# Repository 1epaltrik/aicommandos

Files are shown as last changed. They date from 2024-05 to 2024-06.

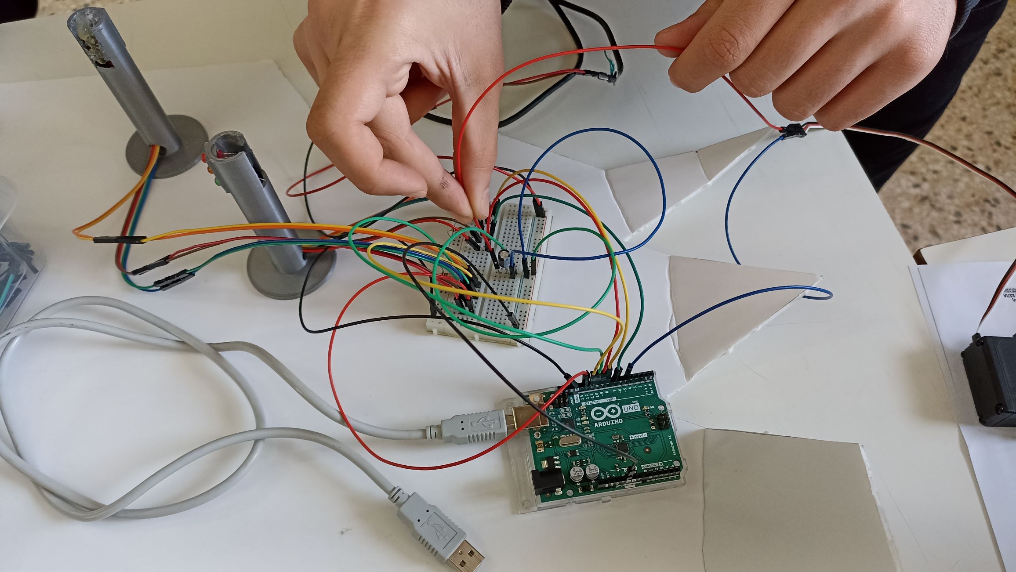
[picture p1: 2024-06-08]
photos/AICommandos13.jpg

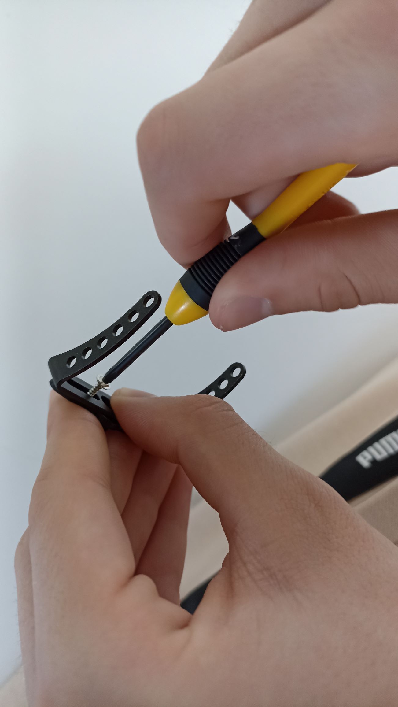
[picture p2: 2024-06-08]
photos/AICommandos12.jpg

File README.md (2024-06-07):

<h1>Ρύθμιση σηματοδοτών κυκλοφορίας
με Τεχνητή Νοημοσύνη</h1>
Είμαστε η ομάδα AI Commandos από το 1ο ΕΠΑΛ Τρικάλων και υλοποιήσαμε το έργο "Ρύθμιση σηματοδοτών κυκλοφορίας με τεχνητή νοημοσύνη".
<h2>Έρευνα</h2>
<h3>Μελέτη υπάρχουσας κατάστασης</h3>
Ένα τεράστιο πρόβλημα των σύγχρονων πόλεων είναι το πρόβλημα της κυκλοφοριακής συμφόρησης, που αφορά όχι μόνο τις μεγάλες μητροπόλεις, αλλά πλέον εμφανίζεται έντονα και στις μικρότερες πόλεις, όπως είναι τα Τρίκαλα.</p>
<p>Ενδεικτικά δείτε το δημοσίευμα: https://trikalain.gr/polys-kosmos-sta-trikala-gia-tis-giortes-tou-pascha-kykloforiako-komfouzio-stous-dromou-tis-polis/</p>
<p>Κυκλοφοριακή συμφόρηση (κοινώς μποτιλιάρισμα) ονομάζεται η κατάσταση στα οδικά δίκτυα που χαρακτηρίζεται από ουρές οχημάτων και χαμηλότερες ταχύτητες μέχρι και ακινησία. Η κυκλοφοριακή συμφόρηση στα αστικά οδικά δίκτυα έχει αυξηθεί σημαντικά από τη δεκαετία του 1950. (Ορισμός από τη Wikipedia).
Οι αρνητικές συνέπειες είναι πολλές: χαμένος χρόνος για οδηγούς και επιβάτες, αυξημένες εκπομπές ρύπων, μεγαλύτερη κατανάλωση καυσίμων, σπατάλη ενέργειας, δημιουργία εκνευρισμού και άγχους, υποβάθμιση της ποιότητας ζωής κλπ.</p>
<h3>Σαφής ορισμός προβλήματος</h3>
<p>Η κυκλοφοριακή συμφόρηση σε μια πόλη μπορεί να προκαλείται από πολλές αιτίες, μία από τις οποίες είναι οι αστικές διασταυρώσεις δύο δρόμων με φανάρια, όπου ο ένας δρόμος έχει μεγαλύτερη κίνηση από τον άλλον.
Σε αυτή την περίπτωση παρατηρείται το φαινόμενο να δημιουργούνται μεγάλες ουρές στο δρόμο με τη μεγαλύτερη κίνηση, ενώ στο δρόμο μικρότερης κίνησης δημιουργούνται μικρές ή και καθόλου ουρές, καθώς ο χρονισμός των φαναριών είναι σταθερός και δεν λαμβάνει υπόψη την τρέχουσα κίνηση σε κάθε δρόμο.</p>
<p>Το φαινόμενο αυτό είναι περισσότερο συνηθισμένο στις μικρές πόλεις, όπως είναι τα Τρίκαλα.</p>

<h2>Σχεδιασμός</h2>
<h3>Σαφής ορισμός προτεινόμενης λύσης</h3>
<p>Η λύση που προτείνουμε είναι να δίνεται προτεραιότητα στο δρόμο που παρατηρείται μεγαλύτερη κίνηση, με κατάλληλη ρύθμιση των φαναριών έτσι ώστε το πράσινο να διαρκεί περισσότερο στο δρόμο μεγαλύτερης κίνησης, για να εκτονώνεται η κυκλοφορία.</p>
<p>Για την αναγνώριση του δρόμου μεγαλύτερης κίνησης δημιουργήσαμε ένα σύστημα με κάμερα και λογισμικό αναγνώρισης οχημάτων, μέσω τεχνικών επεξεργασίας εικόνας και βίντεο και με χρήση τεχνητής νοημοσύνης.</p>
<p>Το σύστημα ελέγχει τον αριθμό των αυτοκινήτων που προστίθενται στην ουρά ενός δρόμου και περιμένουν στο κόκκινο φανάρι. Όταν η ουρά αρχίζει να μεγαλώνει πάνω από ένα όριο, γίνεται ανάλογη ρύθμιση των φωτεινών σηματοδοτών ώστε να αποτραπεί η συμφόρηση.
Πιο συγκεκριμένα αυξάνεται η διάρκεια του πράσινου στο δρόμο με τη μεγαλύτερη ουρά, ενώ μειώνεται στον άλλο δρόμο.</p>
<p>Η κάμερα είναι στερεωμένη πάνω σε βάση και περιστρέφεται με τη βοήθεια ενός κινητήρα, έτσι ώστε να ελέγχει και τους δύο δρόμους της διασταύρωσης. Η κάμερα κοιτάζει πάντα στο δρόμο που έχει κόκκινο για να ελέγχει την ουρά που σχηματίζεται.</p>
<p>Με αυτό τον τρόπο η ρύθμιση των φαναριών επαναλαμβάνεται και προσαρμόζεται δυναμικά ανάλογα με την κίνηση που εμφανίζεται σε κάθε δρόμο της διασταύρωσης.</p>
<h3>Πρωτοτυπία λύσης</h3>
<p>Η χρήση της Τεχνητής Νοημοσύνης είναι προφανώς απαραίτητη σε ένα σύστημα ολοκληρωμένης διαχείρισης του κυκλοφοριακού προβλήματος, όπως φαίνεται και σε διάφορα δημοσιεύματα, για παράδειγμα δείτε: https://www.motori.gr/sto-kokkino-to-kykloforiako-tis-athinas-ta-fanaria-apoktoun-techniti-noimosyni/</p>
<p>Ωστόσο για τη λύση που προτείνουμε δεν βρήκαμε καμία συγκεκριμένη αναφορά, οπότε θεωρούμε ότι είναι πρωτότυπη.</p>
<h3>Κόστος</h3>
<p>Το συνολικό κόστος για το σύστημα ανέρχεται στα 160 ευρώ περίπου.</p>
<h3>Λίστα υλικών και εργαλείων</h3>
<table border=1 cellspacing=0>
<tr><th>Υλικό</th>
<th>Τιμή</th></tr>
<tr><td>Τροφοδοτικό 12V 3A</td>
<td>7.20</td></tr>
<tr><td>Jumper Wires</td>
<td>4.40</td></tr>
<tr><td>Πλακέτα Δοκιμών</td>
<td>3.20</td></tr>
<tr><td>Arduino UNO R4 WiFi</td>
<td>32.80</td></tr>
<tr><td>Servo Standard 7.5kg.cm Metal Gears</td>
<td>16.90</td></tr>
<tr><td>Gravity HUSKYLENS AI Machine Vision Sensor</td>
<td>69.90</td></tr>
<tr><td>Νήμα 3D εκτύπωσης</td>
<td>25.00</td></tr>
</table>

<h3>Σχέδια</h3>
<p>Όλα τα σχέδια του κυκλώματος και των αντικειμένων 3D που εκτυπώσαμε για τη μακέτα είναι αναρτημένα στο <a href="https://github.com/1epaltrik/aicommandos/tree/956ff1dd9cedd848da6d70585bad451899f95dd7/hardware-design"> github</a>.</p>
<h3>Βασικός αλγόριθμος</h3>
<ol>
<li>Αρχικά ορίζουμε αρχικές τιμές για τη διάρκεια των κόκκινων φαναριών, πχ και τα δύο κόκκινα φανάρια να διαρκούν 6 sec.</li>
<li>Αρχίζει η λειτουργία των φαναριών: ανάβει κόκκινο στο δρόμο 1.</li>
<li>Αμέσως η κάμερα περιστρέφεται προς το δρόμο 1 και μετρά τα αυτοκίνητα που περιμένουν στην ουρά.</li>
<li>Αν η ουρά ξεπεράσει έναν αριθμό αυτοκινήτων (πχ 2 στο παράδειγμα επίδειξης), τότε μηδενίζεται ο υπολειπόμενος χρόνος του κόκκινου στο δρόμο 1 και αλλάζουν οι χρονισμοί των φαναριών: στο δρόμο 1 (που παρατηρήθηκε η ουρά) το πράσινο θα διαρκεί περισσότερο, πχ 25 sec, ενώ στον άλλο δρόμο 5 sec.</li>
<li>Συνεχίζεται η ακολουθία των φαναριών: ανάβει κόκκινο στο δρόμο 2.</li>
<li>Η κάμερα περιστρέφεται προς το δρόμο 2 και μετρά τα αυτοκίνητα που περιμένουν στην ουρά.</li>
<li>Ο αλγόριθμος συνεχίζεται με τον ίδιο τρόπο.</li>
</ol>

<h3>Βίντεο</h3>
<p>Δείτε την παρουσίαση του έργου <a href="https://www.youtube.com/watch?v=GHP90vuGQoI" target="_blank">εδώ.</a></p>

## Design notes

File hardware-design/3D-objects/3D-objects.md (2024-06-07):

Εδώ βρίσκονται τα αρχεία STL του TinkerCAD.

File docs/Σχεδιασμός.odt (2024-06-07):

Ρύθμιση σηματοδοτών κυκλοφορίας
με Τεχνητή Νοημοσύνη

Σχεδιασμός

Σαφής ορισμός προτεινόμενης λύσης

Η λύση που προτείνουμε είναι να δίνεται προτεραιότητα στο δρόμο που παρατηρείται μεγαλύτερη κίνηση, με κατάλληλη ρύθμιση των φαναριών έτσι ώστε το πράσινο να διαρκεί περισσότερο στο δρόμο μεγαλύτερης κίνησης, για να εκτονώνεται η κυκλοφορία.

Για την αναγνώριση του δρόμου μεγαλύτερης κίνησης δημιουργήσαμε ένα σύστημα με κάμερα και λογισμικό αναγνώρισης οχημάτων, μέσω τεχνικών επεξεργασίας εικόνας και βίντεο και με χρήση τεχνητής νοημοσύνης.

Το σύστημα ελέγχει τον αριθμό των αυτοκινήτων που προστίθενται στην ουρά ενός δρόμου και περιμένουν στο κόκκινο φανάρι. Όταν η ουρά αρχίζει να μεγαλώνει πάνω από ένα όριο, γίνεται ανάλογη ρύθμιση των φωτεινών σηματοδοτών ώστε να αποτραπεί η συμφόρηση.

Πιο συγκεκριμένα αυξάνεται η διάρκεια του πράσινου στο δρόμο με τη μεγαλύτερη ουρά, ενώ μειώνεται στον άλλο δρόμο.

Η κάμερα είναι στερεωμένη πάνω σε βάση και περιστρέφεται με τη βοήθεια ενός κινητήρα, έτσι ώστε να ελέγχει και τους δύο δρόμους της διασταύρωσης. Η κάμερα κοιτάζει πάντα στο δρόμο που έχει κόκκινο για να ελέγχει την ουρά που σχηματίζεται.

Με αυτό τον τρόπο η ρύθμιση των φαναριών επαναλαμβάνεται και προσαρμόζεται δυναμικά ανάλογα με την κίνηση που εμφανίζεται σε κάθε δρόμο της διασταύρωσης.

Πρωτοτυπία λύσης

Η χρήση της Τεχνητής Νοημοσύνης είναι προφανώς απαραίτητη σε ένα σύστημα ολοκληρωμένης διαχείρισης του κυκλοφοριακού προβλήματος, όπως φαίνεται και σε διάφορα δημοσιεύματα, για παράδειγμα δείτε: https://www.motori.gr/sto-kokkino-to-kykloforiako-tis-athinas-ta-fanaria-apoktoun-techniti-noimosyni/

Ωστόσο για τη λύση που προτείνουμε δεν βρήκαμε καμία συγκεκριμένη αναφορά, οπότε θεωρούμε ότι είναι πρωτότυπη.

Κόστος

Το συνολικό κόστος για το σύστημα ανέρχεται στα 160 ευρώ περίπου.

Λίστα υλικών και εργαλείων

Υλικό | Τιμή
Τροφοδοτικό 12V 3A | 7.20
Jumper Wires | 4.40
Πλακέτα Δοκιμών | 3.20
Arduino UNO R4 WiFi | 32.80
Servo Standard 7.5kg.cm Metal Gears | 16.90
Gravity HUSKYLENS AI Machine Vision Sensor | 69.90
Νήμα 3D εκτύπωσης | 25.00

Σχέδια

Το κύκλωμα του συστήματος φαίνεται στην παρακάτω εικόνα.

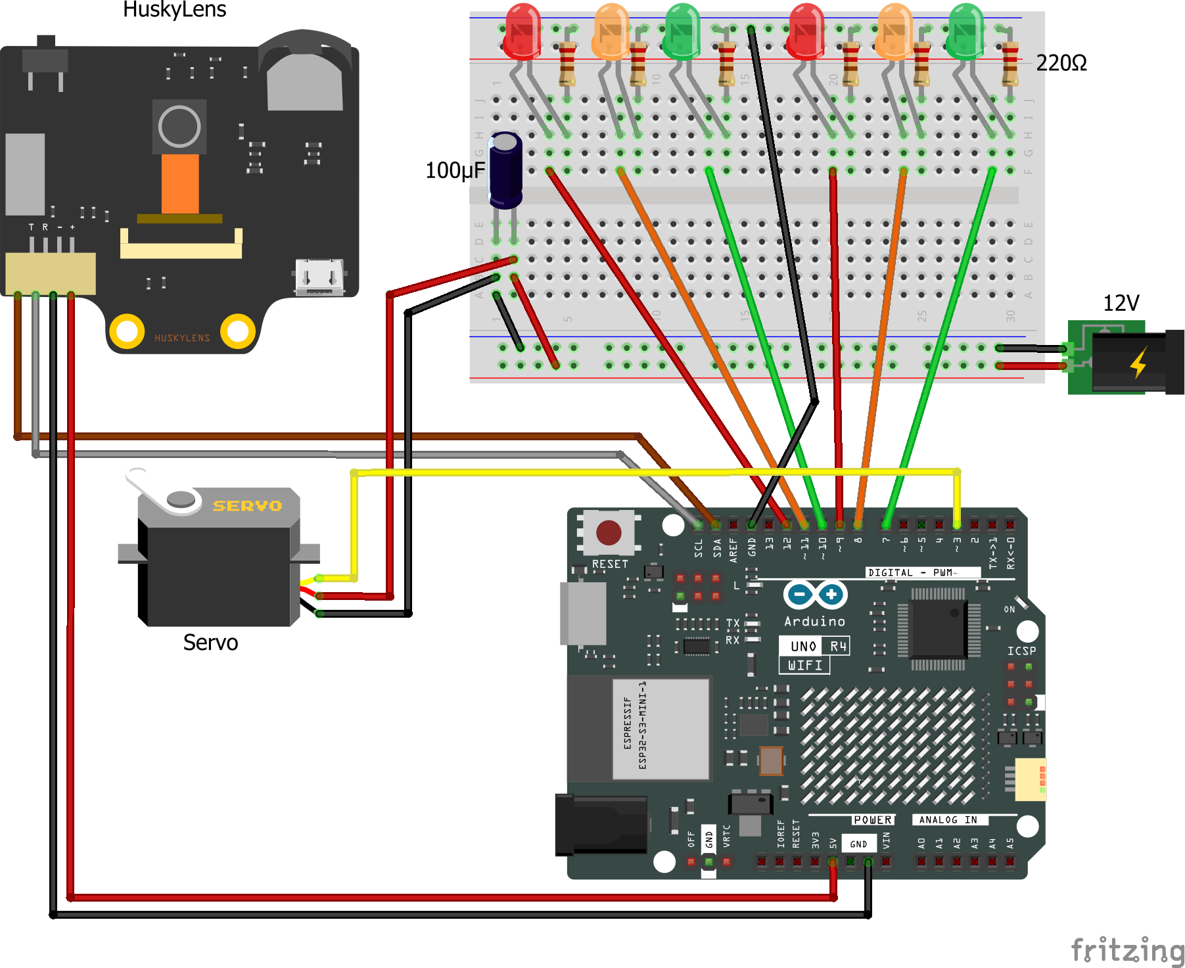
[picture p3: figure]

Όλα τα σχέδια του κυκλώματος και των αντικειμένων 3D που εκτυπώσαμε για τη μακέτα είναι αναρτημένα στο github.

Βασικός αλγόριθμος

1. Αρχικά ορίζουμε αρχικές τιμές για τη διάρκεια των κόκκινων φαναριών, πχ και τα δύο κόκκινα φανάρια να διαρκούν 6 sec.
2. Αρχίζει η λειτουργία των φαναριών: ανάβει κόκκινο στο δρόμο 1.
3. Αμέσως η κάμερα περιστρέφεται προς το δρόμο 1 και μετρά τα αυτοκίνητα που περιμένουν στην ουρά.
4. Αν η ουρά ξεπεράσει έναν αριθμό αυτοκινήτων (πχ 2 στο παράδειγμα επίδειξης), τότε μηδενίζεται ο υπολειπόμενος χρόνος του κόκκινου στο δρόμο 1 και αλλάζουν οι χρονισμοί των φαναριών: στο δρόμο 1 (που παρατηρήθηκε η ουρά) το πράσινο θα διαρκεί περισσότερο, πχ 25 sec, ενώ στον άλλο δρόμο 5 sec.
5. Συνεχίζεται η ακολουθία των φαναριών: ανάβει κόκκινο στο δρόμο 2.
6. Η κάμερα περιστρέφεται προς το δρόμο 2 και μετρά τα αυτοκίνητα που περιμένουν στην ουρά.
7. Ο αλγόριθμος συνεχίζεται με τον ίδιο τρόπο.

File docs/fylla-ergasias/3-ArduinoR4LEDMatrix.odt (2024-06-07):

Φύλλο Εργασίας 3

Οθόνη LED του Arduino R4

Δραστηριότητα 1

Μπείτε στο https://docs.arduino.cc/tutorials/uno-r4-wifi/led-matrix/ και κάντε το παράδειγμα Scrolling Text Example.

Δραστηριότητα 2

Κάντε ένα πρόγραμμα που θα εμφανίζει στο LED Matrix τους αριθμούς από το 0 έως το 99.

Δραστηριότητα 3

Αναπτύξτε το πρόγραμμα έτσι ώστε οι μονοψήφιοι αριθμοί (0-9) να εμφανίζονται στοιχισμένοι δεξιά στο matrix.

Ενδεικτική λύση:

#include "ArduinoGraphics.h"

#include "Arduino_LED_Matrix.h"

ArduinoLEDMatrix matrix;

int x; // οριζόντια μετατόπιση για στοίχιση δεξιά των μονοψήφιων

void setup()

{

// αρχικοποίηση του matrix

matrix.begin();

// Κάνε scroll

matrix.beginDraw();

matrix.stroke(0xFFFFFFFF);

matrix.textScrollSpeed(50);

const char text[] = " 1o EPAL TRIKALON ";

matrix.textFont(Font_5x7);

matrix.beginText(0, 1, 0xFFFFFF);

matrix.println(text);

matrix.endText(SCROLL_LEFT);

matrix.endDraw();

}

void loop()

{

for( int i=0; i<100; i++ )

{

// x: για να στοιχίζονται οι μονοψήφιοι αριθμοί δεξιά

if( i<10 )

x=7;

else

x=2;

matrix.clear();

matrix.beginText(x, 1, 0xFFFFFF);

matrix.println(i);

matrix.endText();

delay(200);

}

}

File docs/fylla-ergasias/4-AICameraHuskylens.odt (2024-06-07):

Φύλλο Εργασίας 4

AI Camera Huskylens

Δραστηριότητα 1

Μπείτε στο https://wiki.dfrobot.com/HUSKYLENS_V1.0_SKU_SEN0305_SEN0336 και μελετήστε τις ενότητες 1.Introduction, 2.Specification και 3.Board Overview

Δραστηριότητα 2

Μελετήστε την ενότητα 7.Functions Introduction και πειραματιστείτε με τις λειτουργίες Object Tracking και Object Recognition.

Δραστηριότητα 3

Μελετήστε την ενότητα 8. Arduino Tutorial και εγκαταστήστε στο Arduino IDE τη βιβλιοθήκη σύμφωνα με τις οδηγίες.

Δραστηριότητα 4

Συνδέστε την κάμερα στο Arduino με τη μέθοδο I2C Mode.

Δραστηριότητα 5

Κάντε το παράδειγμα HUSKYLENS_I2C που θα βρείτε στη διαδρομή Αρχείο->Παραδείγματα->HUSKYLENS του Arduino IDE.

Δραστηριότητα 6

Εκπαιδεύστε την κάμερα έτσι ώστε να αναγνωρίζει ένα αυτοκινητάκι ως car:ID1.

Δραστηριότητα 7

Χρησιμοποιήστε τον ενσωματωμένο αλγόριθμο αναγνώρισης αντικειμένων (ALGORITHM_OBJECT_RECOGNITION) για να μετρήσετε τα αντικείμενα τύπου ID1 (δηλ. αυτοκίνητα) που βλέπει η κάμερα.

Υπόδειξη: Ξεκινήστε από το παράδειγμα HUSKYLENS_ADVANCED και χρησιμοποιήστε μόνο τη λειτουργία που χρειάζεται.

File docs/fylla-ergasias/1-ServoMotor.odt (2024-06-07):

Φύλλο Εργασίας 1

Κινητήρας Servo

Δραστηριότητα 1

Μπείτε στο https://docs.arduino.cc/learn/electronics/servo-motors/ και κάντε τα παραδείγματα Knob και Sweep.

Δραστηριότητα 2

Προγραμματίστε τον κινητήρα Servo έτσι ώστε να περιστρέφεται σε γωνία 90 μοιρών.

Δραστηριότητα 3

Προγραμματίστε δύο συναρτήσεις με ονόματα turnServo1 και turnServo2, από τις οποίες η μία θα περιστρέφει το servo κατά περίπου 90 μοίρες, ενώ η άλλη θα το επαναφέρει στην αρχική του θέση.

Ενδεικτική λύση:

void turnServo1(void)

{

for (int pos = 0; pos <= 120; pos++)

{

myservo.write(pos);

delay(10);

}

}

void turnServo2(void)

{

for (int pos = 120; pos >= 0; pos--)

{

myservo.write(pos);

delay(10);

}

}

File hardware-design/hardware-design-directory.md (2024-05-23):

Εδώ βρίσκονται τα σχέδια των κυκλωμάτων.

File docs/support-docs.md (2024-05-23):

Εδώ βρίσκονται όλα τα έγγραφα τεκμηρίωσης του έργου.

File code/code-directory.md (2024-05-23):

Ο κατάλογος αυτός περιέχει τον κώδικα του έργου.

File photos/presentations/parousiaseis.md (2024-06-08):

Φωτογραφίες από παρουσιάσεις του έργου στην <a href="https://thetalos.ddetrikala.gr/">Ψηφιακή Γιορτή Θε-Ταλώς</a> και στην εκδήλωση <a href=https://1epal-trikal.tri.sch.gr/%cf%84%ce%bf-1%ce%bf-%ce%b5%cf%80%ce%b1%ce%bb-%cf%84%cf%81%ce%b9%ce%ba%ce%ac%ce%bb%cf%89%ce%bd-%cf%83%cf%84%ce%b7%ce%bd-%ce%b5%ce%ba%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>"Ψηφιακός Μετασχηματισμός: Σχεδιάζοντας την πόλη του μέλλοντος"</a>.

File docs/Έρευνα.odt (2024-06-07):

Ρύθμιση σηματοδοτών κυκλοφορίας
με Τεχνητή Νοημοσύνη

Έρευνα

Μελέτη υπάρχουσας κατάστασης

Ένα τεράστιο πρόβλημα των σύγχρονων πόλεων είναι το πρόβλημα της κυκλοφοριακής συμφόρησης, που αφορά όχι μόνο τις μεγάλες μητροπόλεις, αλλά πλέον εμφανίζεται έντονα και στις μικρότερες πόλεις, όπως είναι τα Τρίκαλα.

Ενδεικτικά δείτε το δημοσίευμα: https://trikalain.gr/polys-kosmos-sta-trikala-gia-tis-giortes-tou-pascha-kykloforiako-komfouzio-stous-dromou-tis-polis/

Κυκλοφοριακή συμφόρηση (κοινώς μποτιλιάρισμα) ονομάζεται η κατάσταση στα οδικά δίκτυα που χαρακτηρίζεται από ουρές οχημάτων και χαμηλότερες ταχύτητες μέχρι και ακινησία. Η κυκλοφοριακή συμφόρηση στα αστικά οδικά δίκτυα έχει αυξηθεί σημαντικά από τη δεκαετία του 1950. (Ορισμός από τη Wikipedia (https://el.wikipedia.org/wiki/%CE%9A%CF%85%CE%BA%CE%BB%CE%BF%CF%86%CE%BF%CF%81%CE%B9%CE%B1%CE%BA%CE%AE_%CF%83%CF%85%CE%BC%CF%86%CF%8C%CF%81%CE%B7%CF%83%CE%B7)).

Οι αρνητικές συνέπειες είναι πολλές: χαμένος χρόνος για οδηγούς και επιβάτες, αυξημένες εκπομπές ρύπων, μεγαλύτερη κατανάλωση καυσίμων, σπατάλη ενέργειας, δημιουργία εκνευρισμού και άγχους, υποβάθμιση της ποιότητας ζωής κλπ.

Σαφής ορισμός προβλήματος

Η κυκλοφοριακή συμφόρηση σε μια πόλη μπορεί να προκαλείται από πολλές αιτίες, μία από τις οποίες είναι οι αστικές διασταυρώσεις δύο δρόμων με φανάρια, όπου ο ένας δρόμος έχει μεγαλύτερη κίνηση από τον άλλον.

Σε αυτή την περίπτωση παρατηρείται το φαινόμενο να δημιουργούνται μεγάλες ουρές στο δρόμο με τη μεγαλύτερη κίνηση, ενώ στο δρόμο μικρότερης κίνησης δημιουργούνται μικρές ή και καθόλου ουρές, καθώς ο χρονισμός των φαναριών είναι σταθερός και δεν λαμβάνει υπόψη την τρέχουσα κίνηση σε κάθε δρόμο.

Το φαινόμενο αυτό είναι περισσότερο συνηθισμένο στις μικρές πόλεις, όπως είναι τα Τρίκαλα.

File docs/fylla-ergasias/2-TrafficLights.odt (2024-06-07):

Φύλλο Εργασίας 2

Φανάρια κυκλοφορίας

Δραστηριότητα 1

Κάντε το κλασικό παράδειγμα με ένα φανάρι κυκλοφορίας.

Δραστηριότητα 2

Προσθέστε ένα 2ο φανάρι κυκλοφορίας (σε διαφορετικές θύρες του arduino).

Δραστηριότητα 3

Συγχρονίστε τα δύο φανάρια, όπως είναι σε μια διασταύρωση δύο δρόμων.

Δραστηριότητα 4

Χρησιμοποιήστε μεταβλητές για τους χρόνους που διαρκούν τα φανάρια. Ορίστε αρχικές τιμές αυτών των μεταβλητών, έτσι ώστε τα φανάρια να έχουν τις εξής διάρκειες:

- Πορτοκαλί φανάρια: 1 sec
- Κόκκινο φανάρι (στον 1ο δρόμο): 9 sec
- Κόκκινο φανάρι (στον 2ο δρόμο): 5 sec

Ποιος είναι ο ελάχιστος αριθμός μεταβλητών που μπορείτε να χρησιμοποιήσετε;

Ενδεικτική λύση:

// τα pins των 2 σηματοδοτών L1 και L2

int L1Green = 7;

int L1Orange = 8;

int L1Red = 9;

int L2Green = 10;

int L2Orange = 11;

int L2Red = 12;

int timeOrange = 1000;

int timeL1Red = 9000;

int timeL2Red = 5000;

void loop()

{

digitalWrite(L1Orange, HIGH);

digitalWrite(L2Red, HIGH);

delay(timeOrange);

digitalWrite(L1Orange, LOW);

digitalWrite(L2Red, LOW);

digitalWrite(L1Red, HIGH);

digitalWrite(L2Green, HIGH);

delay(timeL1Red);

digitalWrite(L1Red, LOW);

digitalWrite(L2Green, LOW);

digitalWrite(L1Red, HIGH);

digitalWrite(L2Orange, HIGH);

delay(timeOrange);

digitalWrite(L1Red, LOW);

digitalWrite(L2Orange, LOW);

digitalWrite(L1Green, HIGH);

digitalWrite(L2Red, HIGH);

delay(timeL2Red);

digitalWrite(L1Green, LOW);

digitalWrite(L2Red, LOW);

}

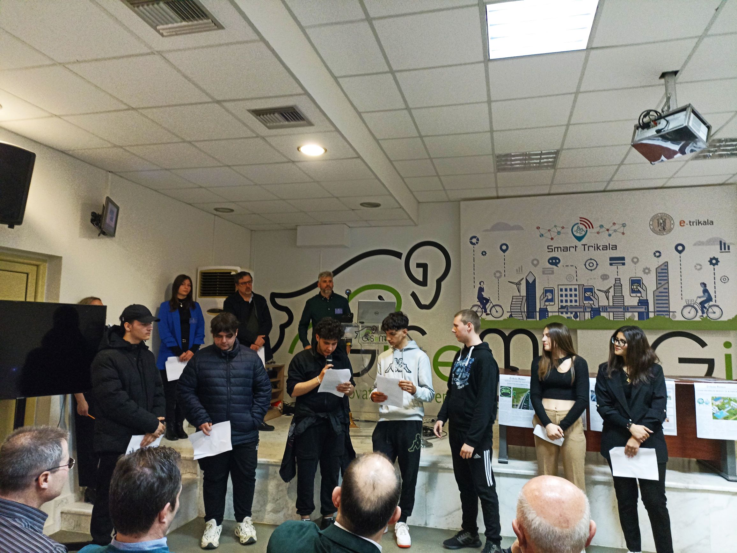
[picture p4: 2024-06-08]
photos/presentations/gisemi2.jpg

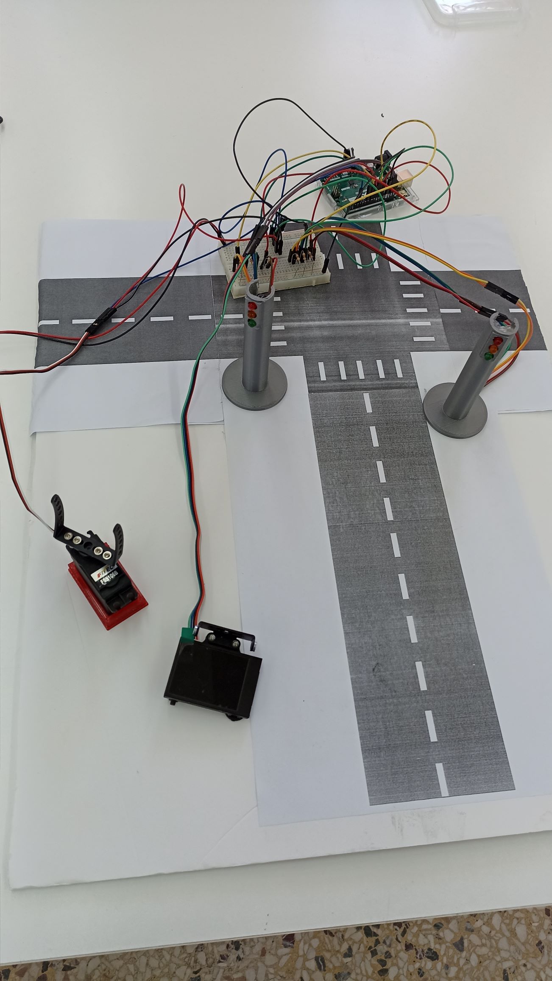
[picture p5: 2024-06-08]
photos/AICommandos7.jpg

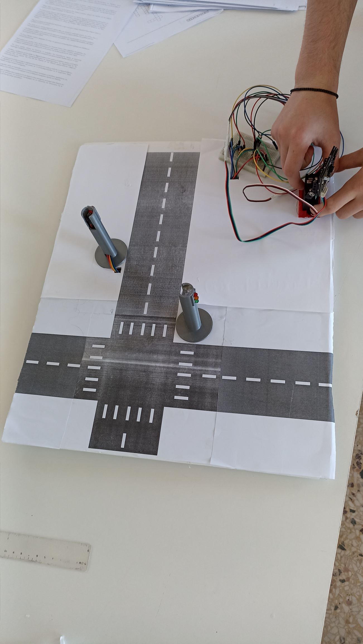
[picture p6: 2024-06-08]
photos/AICommandos1.jpg

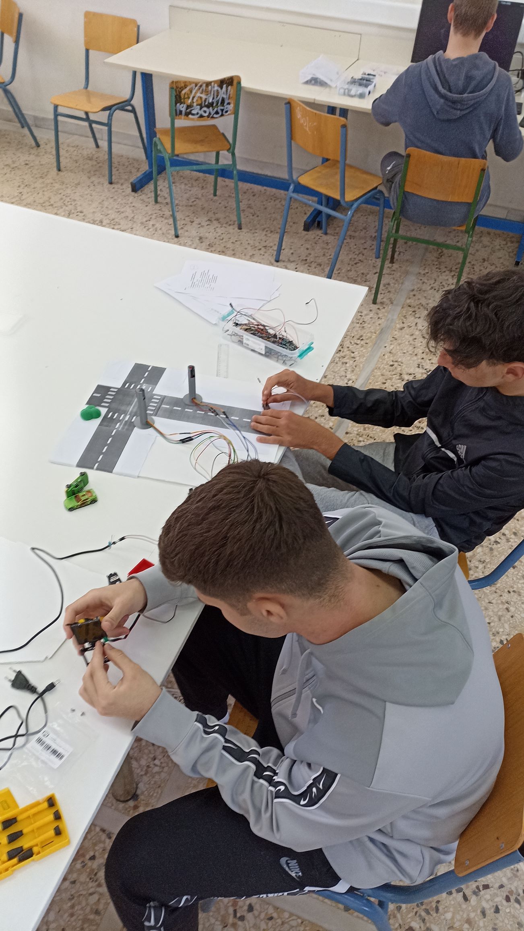
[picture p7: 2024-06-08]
photos/AICommandos5.jpg

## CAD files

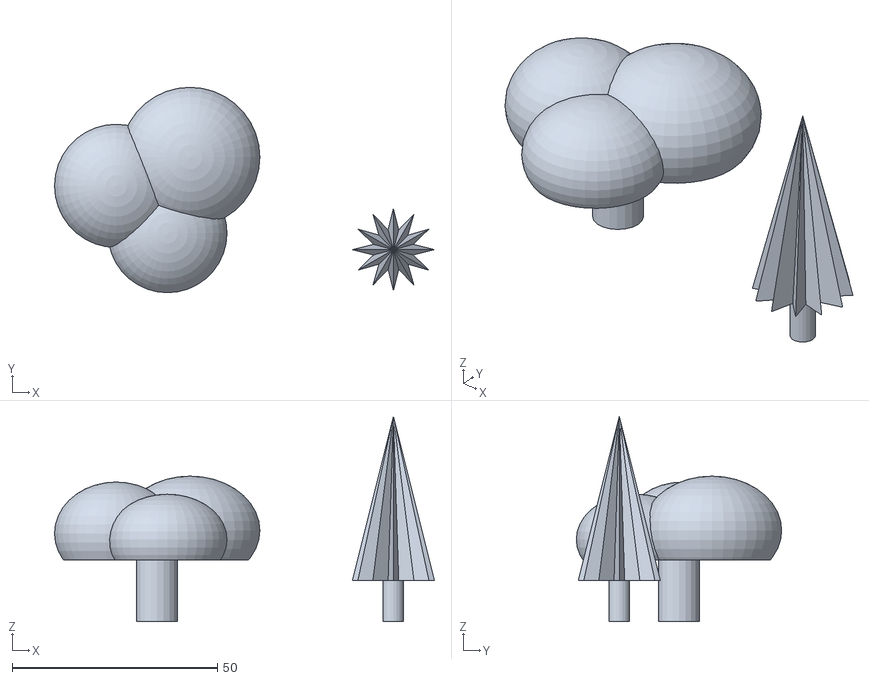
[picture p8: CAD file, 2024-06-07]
hardware-design/3D-objects/Dendra.stl
92.5 x 50.0 x 50.0

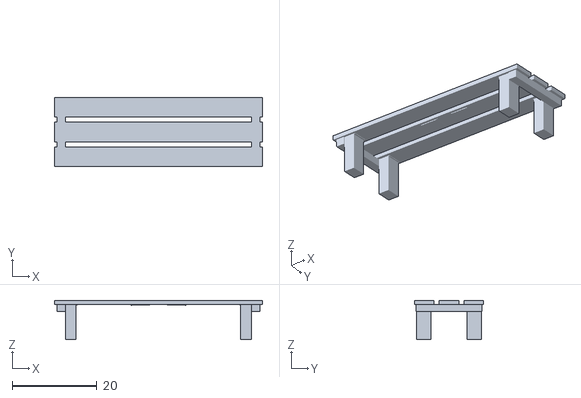
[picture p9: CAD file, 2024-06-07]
hardware-design/3D-objects/bench.stl
49.0 x 16.3 x 9.29

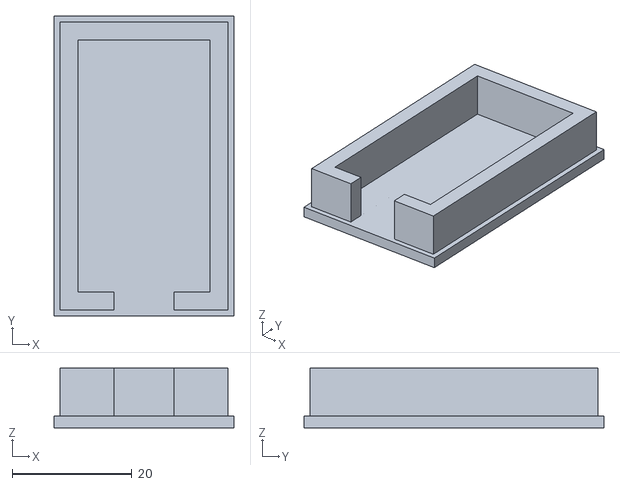
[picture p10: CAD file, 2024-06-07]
hardware-design/3D-objects/Servo Base.stl
30.0 x 50.0 x 10.0

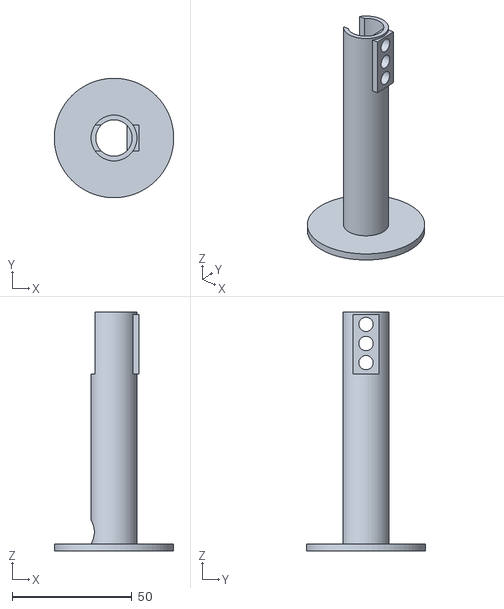
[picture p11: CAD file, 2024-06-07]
hardware-design/3D-objects/Traffic Lights Base.stl
50.0 x 50.0 x 100.0

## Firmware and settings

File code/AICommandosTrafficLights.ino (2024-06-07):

/********************************************************************************
 *  Έλεγχος σηματοδοτών κυκλοφορίας σε διασταύρωση με κάμερα τεχνητής νοημοσύνης,
 *  για αποφυγή κυκλοφοριακής συμφόρησης
 *  
 *  1ο ΕΠΑΛ Τρικάλων - ΕΛΛΑΚ 2024
 *  
 *  Υλικό:
 *  Arduino Uno R4 WiFi (με ενσωματωμένο led matrix)
 *  Camera HuskyLens AI Machine Vision Sensor
 *  Servo Motor
 *********************************************************************************/

// To use ArduinoGraphics APIs, please include BEFORE Arduino_LED_Matrix
// https://www.arduino.cc/reference/en/libraries/arduinographics/
#include "ArduinoGraphics.h"
#include "Arduino_LED_Matrix.h"

ArduinoLEDMatrix matrix;

#include "HUSKYLENS.h"

HUSKYLENS huskylens;
//HUSKYLENS green line >> SDA; blue line >> SCL
int ID1 = 1; //first learned results.

#include <Servo.h>

Servo myservo;  // servo object

int x;  // οριζόντια μετατόπιση για στοίχιση δεξιά των μονοψήφιων αριθμών στο matrix
int lookAtRoad = 1; // μεταβλητή που ορίζει σε ποιον δρόμο (1 ή 2) κοιτάζει η κάμερα

// τα LEDs των 2 σηματοδοτών L1 και L2
int L1Green = 7;
int L1Orange = 8;
int L1Red = 9;
int L2Green = 10;
int L2Orange = 11;
int L2Red = 12;

unsigned long timeNow = 0;      // ο τρέχων χρόνος
unsigned long timeStart = 0;    // η στιγμή που ανάβει το κόκκινο
unsigned long timeStartPerSecond = 0;   // έναρξη της χρονομέτρησης για κάθε 1 sec
int timeToFinishRed;      // υπολειπόμενος χρόνος (sec) για να σβήσει το κόκκινο

int timeOrange = 1000;    // οι αρχικοί χρόνοι που διαρκούν τα φανάρια
int timeL1Red = 6000;
int timeL2Red = 6000;

void setup()
{
  // αρχικοποίηση του led matrix
  matrix.begin();

  // Κάνε scroll τον τίτλο στο led matrix!
  matrix.beginDraw();
  matrix.stroke(0xFFFFFFFF);
  matrix.textScrollSpeed(50);
  const char text[] = "    1o EPAL TRIKALON    ";
  matrix.textFont(Font_5x7);
  matrix.beginText(0, 1, 0xFFFFFF);
  matrix.println(text);
  matrix.endText(SCROLL_LEFT);
  matrix.endDraw();
  
  Serial.begin(115200);
  
  Wire.begin();
  while (!huskylens.begin(Wire))
  {
    Serial.println(F("Begin failed!"));
    Serial.println(F("1.Please recheck the \"Protocol Type\" in HUSKYLENS (General Settings>>Protocol Type>>I2C)"));
    Serial.println(F("2.Please recheck the connection."));
    delay(100);
  }
  // θα χρησιμοποιήσουμε τον ενσωματωμένο αλγόριθμο αναγνώρισης αντικειμένων του HuskyLens
  huskylens.writeAlgorithm(ALGORITHM_OBJECT_RECOGNITION);
  
  myservo.attach(3);  // attaches the servo on pin 3 to the servo object
  
  pinMode( L1Green, OUTPUT);
  pinMode( L1Orange, OUTPUT);
  pinMode( L1Red, OUTPUT);
  pinMode( L2Green, OUTPUT);
  pinMode( L2Orange, OUTPUT);
  pinMode( L2Red, OUTPUT);

  // αναβόσβημα όλων των LED για έλεγχο
  digitalWrite(L1Green, HIGH);
  digitalWrite(L1Orange, HIGH);
  digitalWrite(L1Red, HIGH);
  digitalWrite(L2Green, HIGH);
  digitalWrite(L2Orange, HIGH);
  digitalWrite(L2Red, HIGH);
  delay(1000);
  digitalWrite(L1Green, LOW);
  digitalWrite(L1Orange, LOW);
  digitalWrite(L1Red, LOW);
  digitalWrite(L2Green, LOW);
  digitalWrite(L2Orange, LOW);
  digitalWrite(L2Red, LOW);
  delay(1000);
}

void loop()
{
  clearMatrix();  // πριν το πορτοκαλί καθαρίζουμε τo led matrix
  digitalWrite(L1Orange, HIGH);
  digitalWrite(L2Red, HIGH);
  delay(timeOrange);
  digitalWrite(L1Orange, LOW);
  digitalWrite(L2Red, LOW);
  digitalWrite(L1Red, HIGH);
  digitalWrite(L2Green, HIGH);
  lookRoad1();      // στροφή της κάμερας προς το δρόμο 1
  waitAndCheck(timeL1Red);   // αναμονή μέχρι να τελειώσει ο χρόνος ή να εμφανιστεί ουρά αυτοκινήτων
  clearMatrix();    // πριν το πορτοκαλί καθαρίζουμε τo led matrix
  digitalWrite(L1Red, LOW);
  digitalWrite(L2Green, LOW);
  digitalWrite(L1Red, HIGH);
  digitalWrite(L2Orange, HIGH);
  delay(timeOrange);
  digitalWrite(L1Red, LOW);
  digitalWrite(L2Orange, LOW);
  digitalWrite(L1Green, HIGH);
  digitalWrite(L2Red, HIGH);
  lookRoad2();  // στροφή της κάμερας προς το δρόμο 2
  waitAndCheck(timeL2Red);  // αναμονή μέχρι να τελειώσει ο χρόνος ή να εμφανιστεί ουρά αυτοκινήτων
  digitalWrite(L1Green, LOW);
  digitalWrite(L2Red, LOW);
}

// Το υποπρόγραμμα waitAndCheck δέχεται ως παράμετρο το χρόνο που διαρκεί το κόκκινο.
// Αν κατά τη διάρκεια αυτού του χρόνου η κάμερα εντοπίσει ουρά από 2 αυτοκίνητα, τότε ο χρόνος μηδενίζεται.
// Επίσης εμφανίζει τον υπολειπόμενο χρόνο στο matrix κάθε δευτερόλεπτο.
void waitAndCheck(int t)
{
  timeToFinishRed = t/1000;   // μετατροπή από millisecond σε second
  timeNow = timeStart = timeStartPerSecond = millis();    // αρχικοποίηση χρονομετρητών
  while( timeNow-timeStart < t )
  {
    if( timeNow-timeStartPerSecond>=1000 )    // εκτέλεση κάθε second
    {
      timeStartPerSecond = millis();
      timeToFinishRed--;
      // οριζόντια μετατόπιση x: για να στοιχίζονται οι μονοψήφιοι αριθμοί δεξιά στο led matrix
      if( timeToFinishRed<10 )
        x=7;
      else
        x=2;
      matrix.clear();
      matrix.beginText(x, 1, 0xFFFFFF);
      matrix.println(timeToFinishRed);    // εμφάνιση του υπολειπόμενου χρόνου στο led matrix
      matrix.endText();
    }
    
    if( huskylens.requestBlocks(ID1) )    // έλεγχος για αντικείμενα με ID1 (αυτοκίνητα)
    {
      if( huskylens.countBlocks(ID1) >= 2 )
      {
        Serial.println("Εντοπίστηκαν 2 αυτοκίνητα!!!");
        // Αλλαγή των χρόνων που διαρκούν τα φανάρια
        if( lookAtRoad == 1 )
        {
          timeL2Red = 25000;
          timeL1Red = 5000;
        }
        else if( lookAtRoad == 2 )
        {
          timeL2Red = 5000;
          timeL1Red = 25000;          
        }
        break;  // τέλος του while, οπότε θα αλλάξουν τα φανάρια
      }
    }
    timeNow = millis();
  }
}

// Περιστροφή της κάμερας προς το δρόμο 2
void lookRoad2(void)
{
  for (int pos = 0; pos <= 100; pos++)
  {
    // goes from 0 degrees to 100 degrees in steps of 1 degree
    myservo.write(pos);
    delay(10); 
  }
  lookAtRoad = 2;
}

// Περιστροφή της κάμερας προς το δρόμο 1
void lookRoad1(void)
{
  for (int pos = 100; pos >= 0; pos--)
  {
    // goes from 100 degrees to 0 degrees in steps of 1 degree
    myservo.write(pos);
    delay(10);
  }
  lookAtRoad = 1;
}

// Καθαρισμός του matrix
void clearMatrix()
{
  matrix.clear();
  matrix.beginDraw();
  matrix.endDraw();
}
